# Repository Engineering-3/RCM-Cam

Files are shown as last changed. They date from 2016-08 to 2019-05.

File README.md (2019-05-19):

RCM-Cam
========================

RCM-Cam

This is a camera module for the RCM Control Stack using the OmniVision OV7725 CMOS chip. Please see [Engineering3](http://engineering3.org/) for more information on the complete RCM Control Stack project.

Repository Contents
-------------------

* **/RCM\-Cam\_v1/RCM-Cam\_v1\_24Jan2012/** Gerbers
* **/RCM\-Cam\_v1/** - BOM

Version History
---------------
* [RCM-Cam_v1](https://github.com/Engineering-3/RCM-Cam/tree/master/RCM-Cam_v1) Inital public version v1

License Information
-------------------
Hardware is released under [Solderpad Hardware License v0.51](http://solderpad.org/licenses/SHL-0.51/).
Distributed as-is; no warranty is given.

Getting Started Help
--------------------
This is a Plug-n-Play board.

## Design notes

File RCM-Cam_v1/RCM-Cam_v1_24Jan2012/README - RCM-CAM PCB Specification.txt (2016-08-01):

RCM-CAM PCB Specification
-------------------------------

BOARD STACK:

1. Copper Top
2. Copper Bottom

SILKSCREENS:

1.  Both Layers

PASTE MASKS:

1. Top Layer

BOARD MATERIALS:

RoHS Compliant: YES
Copper: 1oz
Finish: Immersion Gold
Material: FR-406
Thickness: 62 mil
Tg>170
Soldermask: SMOBC BLACK
Silkscreen: White

BOARD TESTING:

Electrical Test: YES

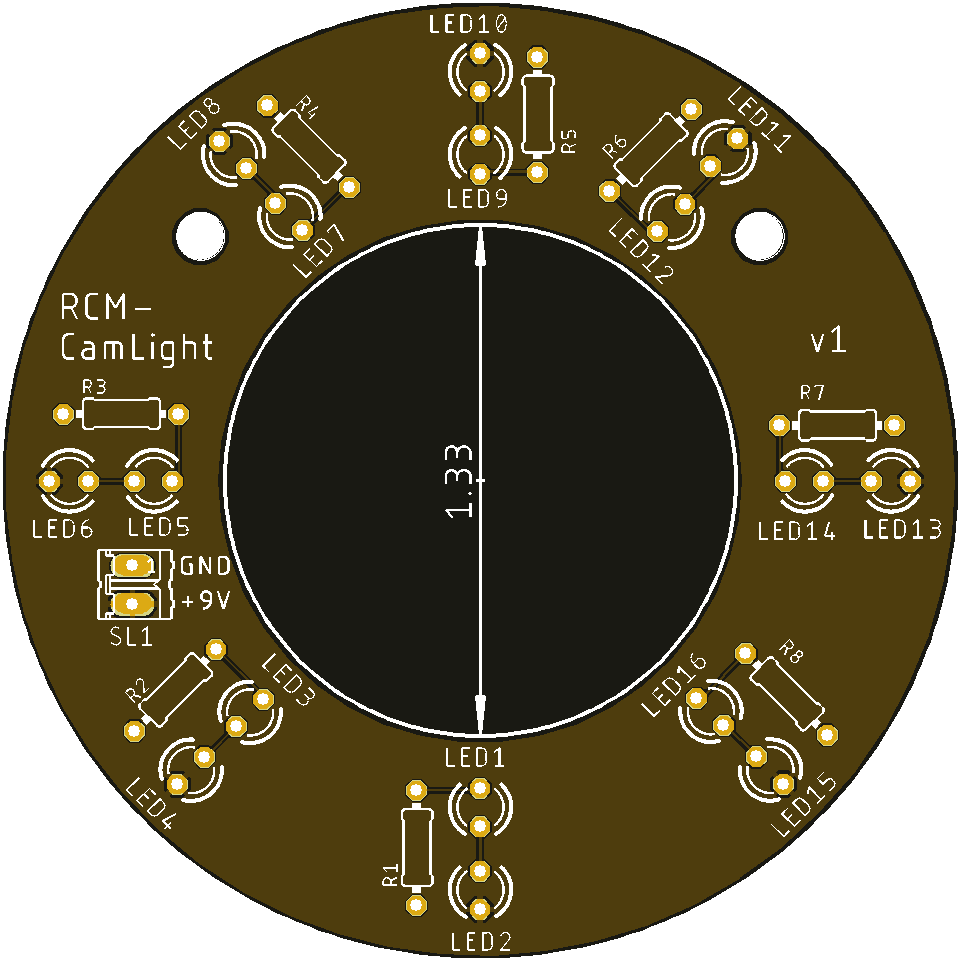
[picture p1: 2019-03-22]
RCM-CamLight_v1/RCM-CamLight_v1_bottom_render.png

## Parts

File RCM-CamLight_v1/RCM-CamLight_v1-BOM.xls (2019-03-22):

* Denotes change from previous Rev.
 |  | PARTS LIST
 |  | ASSY, PCB, IMAGER
 |  |  | <bom_imager_board.xls> | Rev. X5
ITEM | QTY | DESC | MFGR | MFGR'S P/N | Supplier | Supplier PN | NOTES
1 | 16 | LED WHITE CLEAR 3MM T/H | Inolux | INL-3AW30 | Digikey | 1830-1006-ND | LED1, LED2, LED3, LED4, LED5, LED6, LED7, LED8, LED9, LED10, LED11, LED12, LED13, LED14, LED15, LED16
2 |  |  |  |  |  |  | R1, R2, R3, R4, R5, R6, R7, R8
3
4
5

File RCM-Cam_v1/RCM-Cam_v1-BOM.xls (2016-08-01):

* Denotes change from previous Rev.
 |  |  | PARTS LIST
 | P/N |  | ASSY, PCB, IMAGER
 |  |  |  |  |  | <bom_imager_board.xls> | Rev. X5
ITEM | SC P/N | QTY | DESC | Paradigm Stock | Location | MFGR | MFGR'S P/N | Supplier | Supplier PN | NOTES
1 |  | 1 | IC, IMAGER, COLOR, CMOS, VGA (640x480), BGA, 28 Pin | N/A |  | Omni Vision | OV07725-V28A | Nu Horizons | OV07725-V28A | U1
2 |  | 1 | HEADER, DIP, STRAIGHT, 32 PIN, THRU HOLE | 2011-2X40G00SB | T-06-16 | Oupiin | 2011-2X40G00SB | Oupiin | 2011-2X40G00SB | J1 (use 40-pin, cut to 32-pin)
3 |  | 1 | IC, REGULATOR LDO, POSITIVE, SMD, SOT25 | N/A |  | Torex | XC6204B182MR-G | Digikey | 893-1060-1-ND | U2
*4 |  | 4 | TRANS, MOSFET, N-CH, SMD, SOT23 | N/A |  | Fairchild | BSS138 | Digikey | BSS138CT-ND | Q1, Q2, Q3, Q4
5 |  | 1 | PCB, IMAGER | N/A |  | TBD | TBD
*6 |  | 4 | RES, CHIP, 0 OHM JUMPER, 0.06W, 0805 | NRC10Z0TRF | S-CE-05 | Vishay | CRCW08050000Z0EA | Digikey | 541-0.0ACT-ND | R2, R3, R4, R10,
7 |  | 1 | RES, CHIP, 4.7K 5%, 0.06W, 0805 | RK73B2ATTD472J | S-ZC-05 | Vishay | CRCW08054K70JNEA | Digikey | 541-4.7KACT-ND | R1
8 |  | 2 | CAP, TANT, 10uF 10% 10V, A SIZE | N/A |  | AVX | TAJA106K010RNJ | Digikey | 478-1654-1-ND | C2, C22
9 |  | 7 | CAP, CHIP, 0.1uF 10%, 50V X7R, 0805 | C0805C104K5RACTU | S-CD-07 | AVX | 08055C104KAT2A | Digikey | 78-1395-1-ND | C1, C3, C16, C17, C18, C19, C20
10 |  | 1 | CAP, TANT, 4.7uF 10% 10V, A SIZE | T491A475K016AS | S-EA-03 | AVX | TAJR475K010RNJ | Digikey | 478-3280-1-ND | C7
11 |  | 1 | CAP, CHIP, 1uF 10%, 50V X5R, 0805 | N/A |  | AVX | 08055D105KAT2A | Digikey | 478-5995-1-ND | C5
*12 |  | 2 | RES, CHIP, 100 OHM 5%, 0.06W, 0805 | NRC10J101TR | S-AB-11 | Vishay | CRCW0805100RJNEA | Digikey | 541-100ACT-ND | R8, R9
*13 |  | 4 | RES, CHIP, 10 OHM 5%, 0.06W, 0805 | CRCW080510R0JNTA | S-BC-10 | Vishay | CRCW080510R0JNEA | Digikey | 541-10ACT-ND | R5, R6, R7, R15
14 |  | 0 | LED, PCB MOUNT, T-1 STRAIGHT, WHITE |  |  | TBD | TBD |  |  | D1, D2, D3, D4 (Customer Install)
15 |  | 0 | LED, PCB MOUNT, T-1 STRAIGHT, IR |  |  | TBD | TBD |  |  | D5, D6, D7, D8 (Customer Install)
16 |  | 1 | LENS, |  |  | Marshall Optical | V-4303.6-1
17 |  | 1 | LENS HOLDER, |  |  | Marshall Optical | V-LH4-IR
*18 |  | 3 | SCR,MACH,M2X5MM,PAN,PH,ST,ZN | N/A |  | McMaster | 92005A019
 |  | 35
 |  | 29

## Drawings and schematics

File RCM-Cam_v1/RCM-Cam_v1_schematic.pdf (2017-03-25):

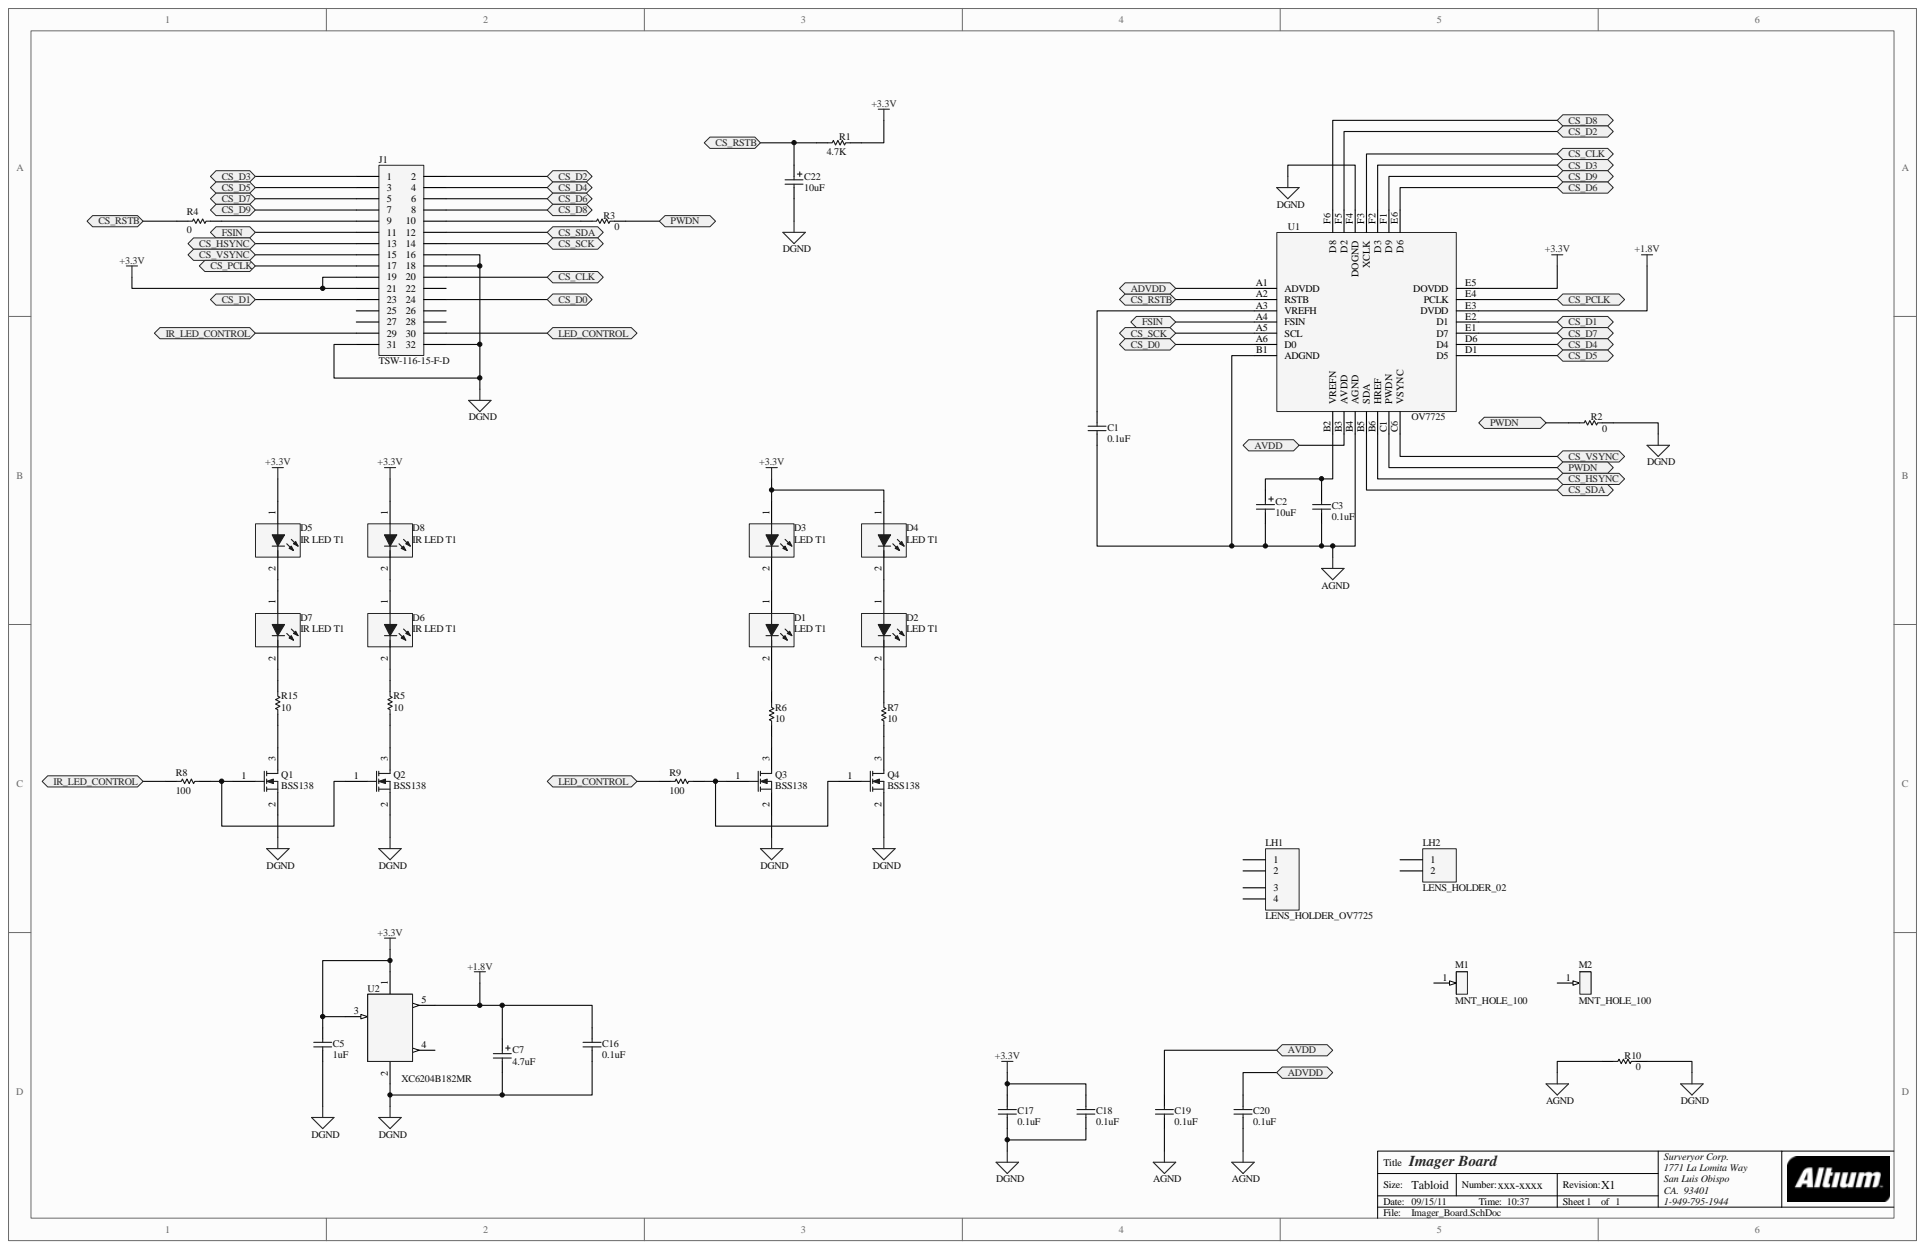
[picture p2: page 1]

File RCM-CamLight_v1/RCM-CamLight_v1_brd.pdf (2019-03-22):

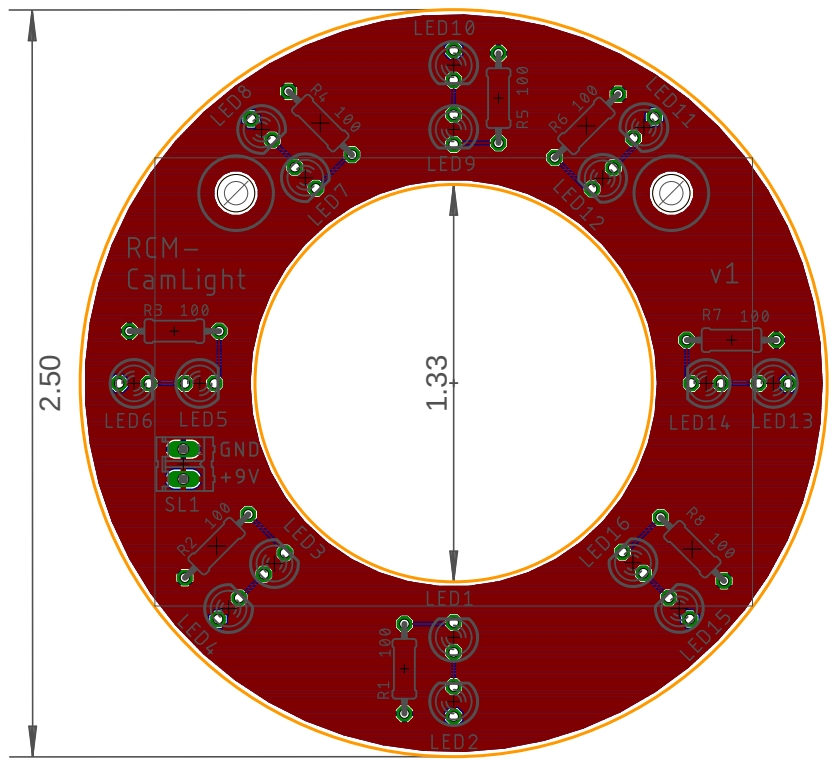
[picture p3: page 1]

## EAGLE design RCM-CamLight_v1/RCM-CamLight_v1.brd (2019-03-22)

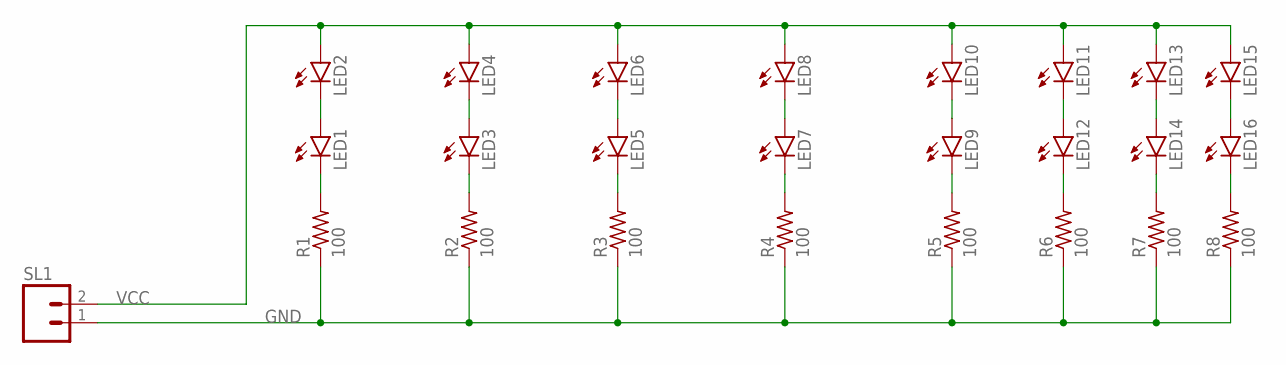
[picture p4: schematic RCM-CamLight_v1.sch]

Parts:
LED1, LED2, LED3, LED4, LED5, LED6, LED7, LED8, LED9, LED10, LED11, LED12, LED13, LED14, LED15, LED16: LED3MM
R1, R2, R3, R4, R5, R6, R7, R8: 100; 0204/7
SL1: M02; 02P

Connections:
GND: R1.1, R2.1, R3.1, R4.1, R5.1, R6.1, R7.1, R8.1, SL1.1
unnamed: LED9.A, LED10.K (C)
unnamed: LED12.K (C), R6.2
unnamed: LED1.K (C), R1.2
unnamed: LED1.A, LED2.K (C)
unnamed: LED3.A, LED4.K (C)
unnamed: LED3.K (C), R2.2
unnamed: LED5.K (C), R3.2
unnamed: LED5.A, LED6.K (C)
unnamed: LED7.A, LED8.K (C)
unnamed: LED7.K (C), R4.2
unnamed: LED9.K (C), R5.2
unnamed: LED14.K (C), R7.2
unnamed: LED11.K (C), LED12.A
unnamed: LED16.K (C), R8.2
unnamed: LED15.K (C), LED16.A
unnamed: LED13.K (C), LED14.A
VCC: LED2.A, LED4.A, LED6.A, LED8.A, LED10.A, LED11.A, LED13.A, LED15.A, SL1.2

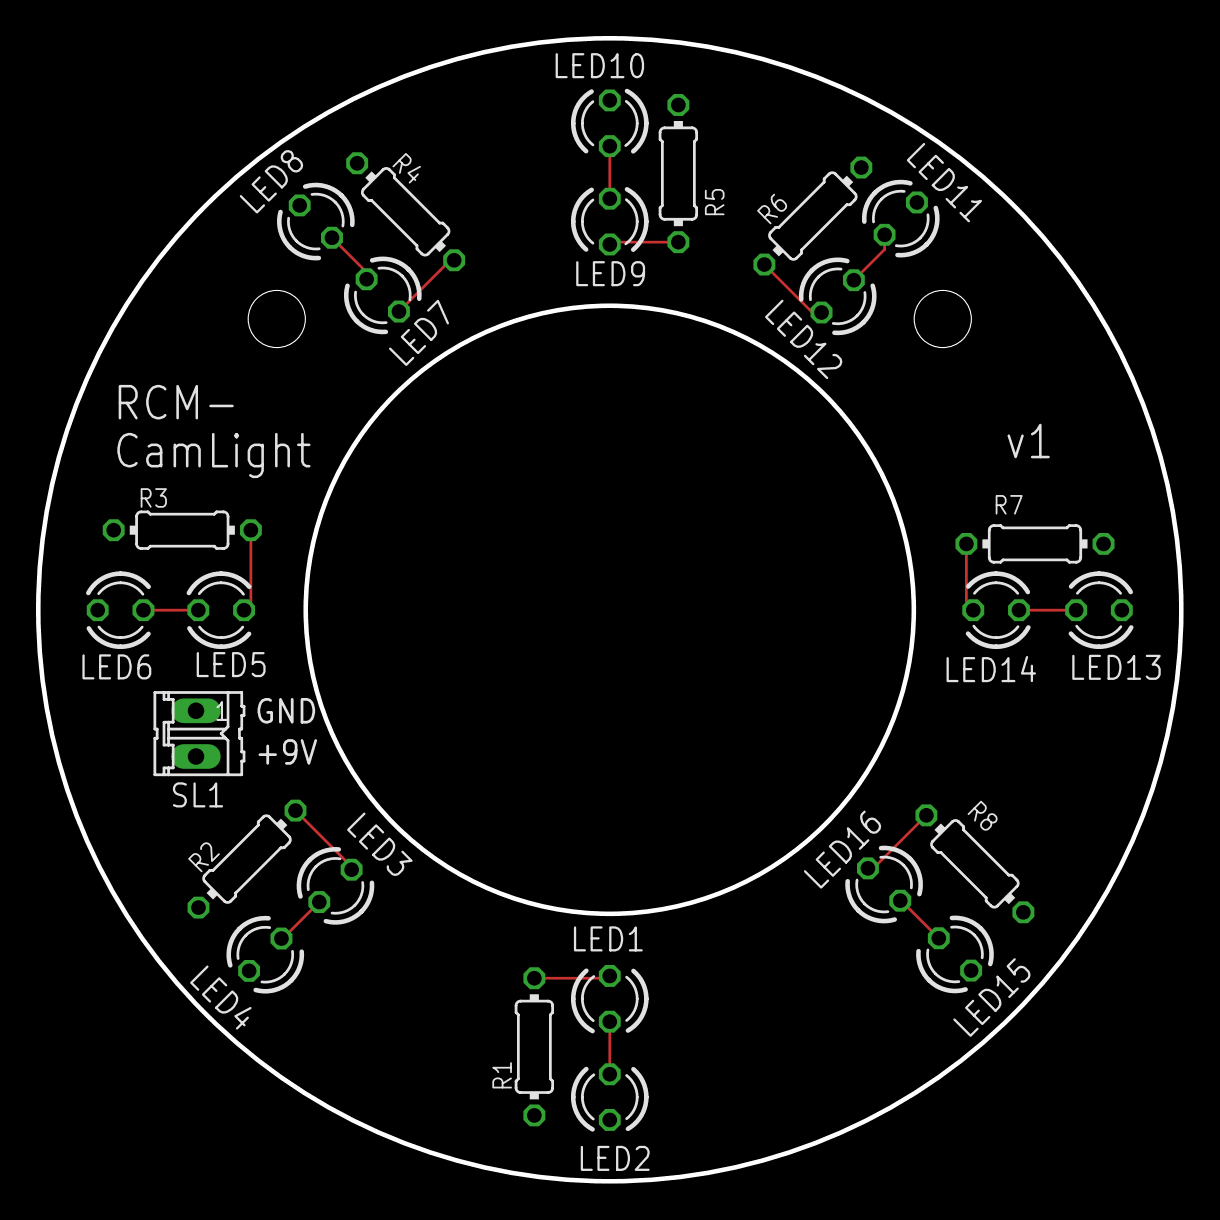
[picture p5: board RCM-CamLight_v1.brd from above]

Board: 2 copper layers, 63.5 x 63.5 mm, 25 parts (0 on the bottom side), 18 nets.

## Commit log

2015-02-17 Initial file checkin.
    [RCM-Cam_v1_B.DRL, RCM-Cam_v1_B.GBL, RCM-Cam_v1_B.GBO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]
2016-02-11 Removed incorrect BOM file, replaced with correct BOM file.
    [RCM-Cam_v1-BOM.xls, pcm bom BF537_v1.1.xls]
2016-08-01 Adding board build readme
    [RCM-Cam_v1-BOM.xls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]
2017-03-25 Adding schematic for RCM-CAM v1.
2019-03-22 RCM-CamLight v1 board added
    [RCM-CamLight_v1-BOM.xls, RCM-CamLight_v1.brd, RCM-CamLight_v1.sch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]
